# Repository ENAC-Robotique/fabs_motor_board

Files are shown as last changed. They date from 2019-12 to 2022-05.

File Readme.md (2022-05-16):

# Motor control board

STM32F767 based motor control board.

- control up to 3 DC motors
- 4 hardware encoder inputs.

**Holonomic drive:** Use the 3 motors, and the first 3 encoders.

**Differential drive:** Use the first 2 motors. Use the first 2 encodeurs for the motor encodeurs, and the last 2 for the odometry wheels (if applicable).

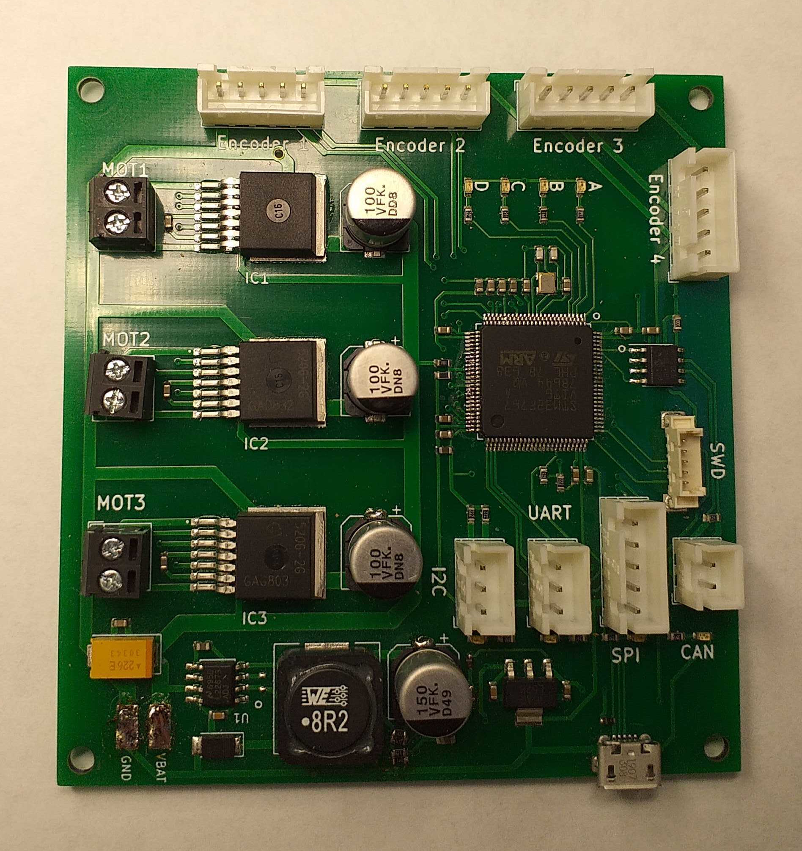
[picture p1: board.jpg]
board


Fetch all submodules with:

`git submodule update --init --recursive`

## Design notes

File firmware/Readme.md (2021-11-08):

Testeur software
================

To build the firmware, there is few thing you need to have.

First, Fetch ChibiOs and some third party contributions with `git submodule update --init --recursive`.

__Install Perl dependencies (used to generate board.h file from board.cfg):__

```
sudo apt update
sudo apt install libmodern-perl-perl libxml-libxml-perl
sudo perl -MCPAN -e 'install String::LCSS'
```

__Install GCC for ARM:__

`sudo apt install gcc-arm-none-eabi gdb-multiarch`

__Install STM32CubeMX__

Download and install SMT32CubeMx with admin rights (need to signup on st.com): [http://www.st.com/en/development-tools/stm32cubemx.html](http://www.st.com/en/development-tools/stm32cubemx.html).

Make sure it is installed in `/usr/local` for linux users (_not_ in your $HOME) or `C:\Program Files` for windows users.

Protobuf
--------

This firmware uses EmbeddedProto. See https://github.com/Embedded-AMS/EmbeddedProto

`git submodule update --init --recursive`

You need to install `protobuf-compiler`: `sudo apt install protobuf-compiler`

Then you need to run: `cd EmbeddedProto && ./setup.sh`

Run `make generate` to generate source code from protobuf files.

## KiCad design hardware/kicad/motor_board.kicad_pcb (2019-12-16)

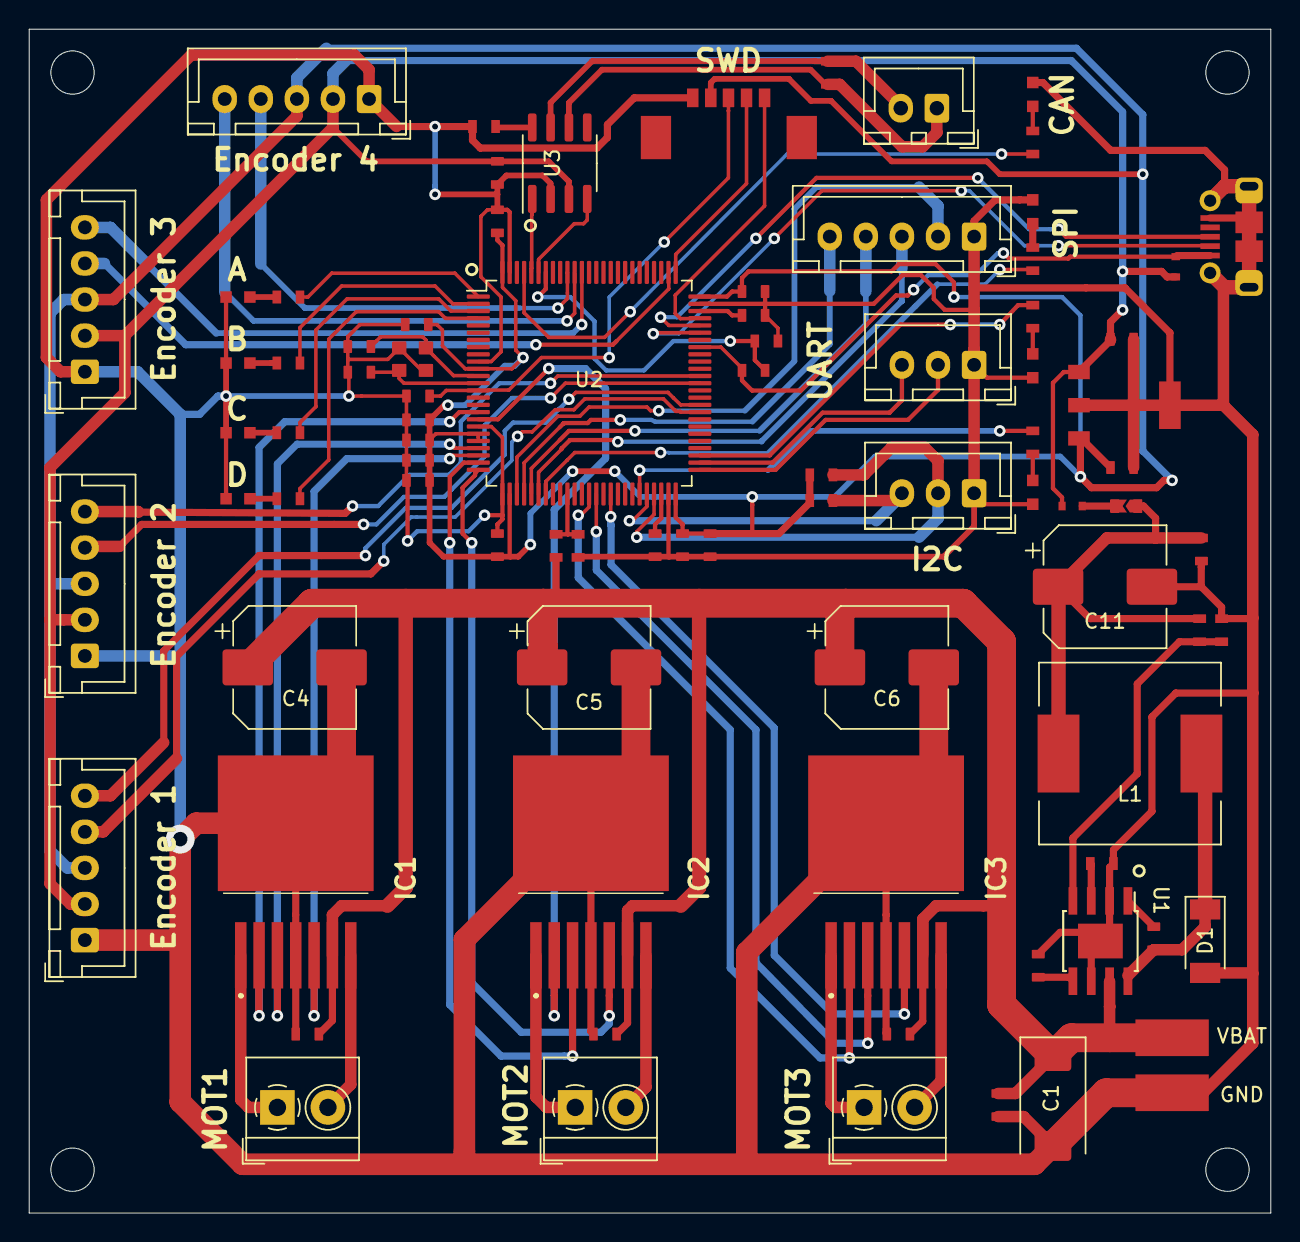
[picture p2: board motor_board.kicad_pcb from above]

Board: 2 copper layers, 86.0 x 82.0 mm, 84 parts (0 on the bottom side), 75 nets.

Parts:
C1: 22uF; CP_EIA-7343-31_Kemet-D
C2: 6.8nF; C_0603
C3, C12, C26, C28: 1uF; C_0603
C4, C5, C6: 100uF; CP_Elec_8x10
C7, C8, C9, C17, C19, C21, C22, C23, C25, C27, C29, C30: 100nF; C_0603
C10: 10nF; C_0603
C11: 120uF; CP_Elec_8x10
C13, C14: 2.2uF; C_0603
C15, C16: 18pF; C_0603
C18: 4.7uF; C_0603
C20: 470nF; C_0603
C24: 330nF; C_0603
D1: PMEG4050ETP; D_SOD-128
D2, D3: PMEG2010EB
IC1, IC2, IC3: TLE52062GAUMA1; TLE52052GAUMA1
IC4: LM3940IMP-3.3; LM3940IMP
J1: MOT1; TerminalBlock_4Ucon_1x02_P3.50mm_Horizontal
J2: MOT2; TerminalBlock_4Ucon_1x02_P3.50mm_Horizontal
J3: MOT3; TerminalBlock_4Ucon_1x02_P3.50mm_Horizontal
J4: UART; JST_XH_B3B-XH-A_1x03_P2.50mm_Vertical
J5: I2C; JST_XH_B3B-XH-A_1x03_P2.50mm_Vertical
J6: USB_Micro-B_Rec; USB_Micro-B_Molex_105017-0001
J7: ENC2; JST_XH_B5B-XH-A_1x05_P2.50mm_Vertical
J8: ENC3; JST_XH_B5B-XH-A_1x05_P2.50mm_Vertical
J9: ENC4; JST_XH_B5B-XH-A_1x05_P2.50mm_Vertical
J10: ENC8; JST_XH_B5B-XH-A_1x05_P2.50mm_Vertical
J11: SWD; PicoBlade_53398-0571
J12: SPI; JST_XH_B5B-XH-A_1x05_P2.50mm_Vertical
J13: CAN; JST_XH_B2B-XH-A_1x02_P2.50mm_Vertical
JP1: SolderJumper_2P; SolderJumper_2P_TrianglePads_0603
L1: 8.2uH; L_Wuerth_WE-PD-Typ-LS
LED1: KP-1608CGCK
LED2, LED5, LED6, LED7, LED8: KP-1608SYC
LED3: KP-1608SURC
LED4: KP-1608SEC
P1: Power_pads
Q1: 8Z_16MHz; Crystal_8Z
R1: infΩ; R_0603
R2, R3, R4: 1.5KΩ; R_0603
R5, R10: 2.2KΩ; R_0603
R6, R7, R8, R9, R13, R14, R17, R18: 390Ω; R_0603
R11: 10KΩ; R_0603
R12: 0Ω; R_0603
R15, R16: 2.2kΩ; R_0603
R19: 120Ω; R_0603
U1: LM22673MRE-ADJ; TI_SO-PowerPAD-8
U2: STM32F767VITx; LQFP-100_14x14mm_P0.5mm
U3: MCP2551-I-SN; SOIC-8_3.9x4.9mm_P1.27mm

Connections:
+3V3: C18.2, C19.2, C21.2, C22.2, C23.2, C24.1, C25.2, C26.2, C27.2, C28.1, C29.1, IC4.3, J7.3, J8.3, J9.3, J10.3, J11.2, R15.1, R16.1, U2.11, U2.20, U2.21, U2.27, U2.50, U2.75, U2.100
+5V: C20.1, C30.2, D2.1, D3.1, IC4.1, J7.2, J8.2, J9.2, J10.2, U3.3
/ADC_POWER: R10.1, R11.1, U2.35
/CAN1_RX: U2.95, U3.4
/CAN1_TX: U2.96, U3.1
/CANH: J13.2, R19.2, U3.7
/CANL: J13.1, R19.1, U3.6
/ENC2A: J7.4, U2.77
/ENC2B: J7.5, U2.89
/ENC3A: J8.5, U2.90
/ENC3B: J8.4, U2.91
/ENC4A: J9.4, U2.59
/ENC4B: J9.5, U2.60
/ENC8A: J10.4, U2.63
/ENC8B: J10.5, U2.64
/I2C2_SCL: J5.3, R15.2, U2.46
/I2C2_SDA: J5.2, R16.2, U2.47
/LED1: R6.2, U2.1
/LED2: R7.2, U2.2
/LED3: R9.2, U2.3
/LED4: R8.2, U2.4
/LED_CAN: R14.2, U2.97
/LED_I2C: R18.2, U2.45
/LED_SPI: R17.2, U2.32
/LED_UART: R13.2, U2.53
/NRST: C17.2, J11.3, U2.14
/PWM1A: IC1.3, U2.22
/PWM1B: IC1.5, U2.23
/PWM2A: IC2.3, U2.24
/PWM2B: IC2.5, U2.25
/PWM3A: IC3.3, U2.39
/PWM3B: IC3.5, U2.41
/SPI1_MISO: J12.4, U2.30
/SPI1_MOSI: J12.3, U2.31
/SPI1_NSS: J12.2, U2.28
/SPI1_SCK: J12.5, U2.29
/SWDCLK: J11.4, U2.76
/SWDIO: J11.5, U2.72
/TLE_EF_1: IC1.2, U2.17
/TLE_EF_2: IC2.2, U2.18
/TLE_EF_3: IC3.2, U2.38
/UART5_RX: J4.2, U2.51
/UART5_TX: J4.3, U2.52
/USB_DM: J6.2, U2.70
/USB_DP: J6.3, U2.71
/USB_VBUS: D3.2, J6.1, R4.2, U2.68
GND: C1.2, C2.1, C3.1, C4.2, C5.2, C6.2, C7.1, C8.1, C9.1, C11.2, C12.1, C13.2, C14.2, C15.1, C16.2, C17.1, C18.1, C19.1, C20.2, C21.1, C22.1, C23.1, C24.2, C25.1, C26.1, C27.1, C28.2, C29.2, C30.1, D1.2, IC1.4, IC1.8, IC2.4, IC2.8, IC3.4, IC3.8, IC4.2, IC4.4, J4.1, J5.1, J6.5, J6.6, J7.1, J8.1, J9.1, J10.1, J11.1, J12.1, LED1.1, LED2.1, LED3.1, LED4.1, LED5.1, LED6.1, LED7.1, LED8.1, P1.1, Q1.2, Q1.4, R1.1, R3.2, R5.1, R10.2, R12.2, U1.2, U1.6, U1.9, U2.10, U2.19, U2.26, U2.49, U2.74, U2.99, U3.2
unnamed: C3.2, U1.5
unnamed: C10.1, U1.1
unnamed: C10.2, D1.1, L1.1, U1.8
unnamed: C11.1, C12.2, JP1.1, L1.2, R2.1
unnamed: C13.1, U2.48
unnamed: C14.1, U2.73
unnamed: C15.2, Q1.1, U2.12
unnamed: C16.1, Q1.3, U2.13
unnamed: D2.2, JP1.2
unnamed: IC1.1, J1.1
unnamed: IC1.7, J1.2
unnamed: IC2.1, J2.1
unnamed: IC2.7, J2.2
unnamed: IC3.1, J3.1
unnamed: IC3.7, J3.2
unnamed: LED1.2, R6.1
unnamed: LED2.2, R7.1
unnamed: LED3.2, R8.1
unnamed: LED4.2, R9.1
unnamed: LED5.2, R13.1
unnamed: LED6.2, R14.1
unnamed: LED7.2, R17.1
unnamed: LED8.2, R18.1
unnamed: R1.2, U1.3
unnamed: R2.2, R3.1, U1.4
unnamed: R4.1, R5.2, U2.94
unnamed: R12.1, U3.8
VBAT: C1.1, C2.2, C4.1, C5.1, C6.1, C7.2, C8.2, C9.2, IC1.6, IC2.6, IC3.6, P1.2, R11.2, U1.7

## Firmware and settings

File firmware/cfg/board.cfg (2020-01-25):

MCU_MODEL = STM32F767VITx
#MCU_MODEL = STM32F767VGTx
CHIBIOS_VERSION = 3.0

HEADER
/*
 * Board identifier.
 */
#define BOARD_MOT_TRD
#define BOARD_NAME                  "Motor Board The Rusty Ducks V0.1"

/*
 * Board oscillators-related settings.
 */
#if !defined(STM32_LSECLK)
#define STM32_LSECLK                32768U
#endif

#define STM32_LSEDRV                (3U << 3U)

#if !defined(STM32_HSECLK)
#define STM32_HSECLK                16000000U
#endif

/*
 * Board voltages.
 * Required for performance limits calculation.
 */
#define STM32_VDD                   300U

/*
 * MCU type as defined in the ST header.
 */
#define STM32F767xx

CONFIG


# PIN NAME PERIPH_TYPE AF_NUMBER or
# PIN NAME FUNCTION PP_or_OPENDRAIN PIN_SPEED PULL_RESISTOR INITIAL_LEVEL AF_NUMBER
# SPEED : SPEED_VERYLOW, SPEED_LOW, SPEED_MEDIUM, SPEED_HIGH
#
# DEFAULT AND SYS
# 
# 'SYS' => ['ALTERNATE', 'PUSHPULL', 'SPEED_HIGH', 'FLOATING', 'LEVEL_HIGH'],
# 'ADC' => ['ANALOG', 'PUSHPULL', 'SPEED_HIGH', 'FLOATING', 'LEVEL_LOW'],
# 'PWM' => ['ALTERNATE', 'PUSHPULL', 'SPEED_HIGH', 'FLOATING', 'LEVEL_LOW'],
# 'ICU' => ['ALTERNATE', 'PUSHPULL', 'SPEED_HIGH', 'FLOATING', 'LEVEL_HIGH'],
# 'I2C' => ['ALTERNATE', 'OPENDRAIN', 'SPEED_HIGH', 'PULLUP', 'LEVEL_HIGH'],
# 'SPI' => ['ALTERNATE', 'PUSHPULL', 'SPEED_HIGH', 'FLOATING', 'LEVEL_HIGH'],
# 'UART' => ['ALTERNATE', 'PUSHPULL', 'SPEED_HIGH', 'PULLUP', 'LEVEL_HIGH'],
# 'OTG' => ['ALTERNATE', 'PUSHPULL', 'SPEED_HIGH', 'FLOATING', 'LEVEL_HIGH'],
# 'ETH' => ['ALTERNATE', 'PUSHPULL', 'SPEED_HIGH', 'FLOATING', 'LEVEL_HIGH'],
# 'FSMC' => ['ALTERNATE', 'PUSHPULL', 'SPEED_HIGH', 'FLOATING', 'LEVEL_HIGH'],
# 'SDIO' => ['ALTERNATE', 'PUSHPULL', 'SPEED_HIGH', 'PULLUP', 'LEVEL_HIGH'],
# 'SDIOCK' => ['ALTERNATE', 'PUSHPULL', 'SPEED_HIGH', 'FLOATING', 'LEVEL_HIGH'],
# 'CAN' => ['ALTERNATE', 'PUSHPULL', 'SPEED_HIGH', 'FLOATING', 'LEVEL_HIGH'],
# 'DCMI' => ['ALTERNATE', 'PUSHPULL', 'SPEED_HIGH', 'FLOATING', 'LEVEL_HIGH'],
# 'LED' => ['OUTPUT', 'PUSHPULL', 'SPEED_VERYLOW', 'FLOATING', 'LEVEL_LOW'],
# 'PASSIVE' => ['INPUT', 'PUSHPULL', 'SPEED_VERYLOW', 'FLOATING', 'LEVEL_LOW']);
#
# SYSTEM
A13     SWDIO     SYS  AF:SYS_JTMS-SWDIO
A14     SWCLK     SYS  AF:SYS_JTCK-SWCLK
#C14     OSC32_IN  OSC  
#C15     OSC32_OUT OSC  
H00     OSC_IN    OSC  
H01     OSC_OUT   OSC  

#DEFAULT
DEFAULT                 INPUT   PUSHPULL SPEED_VERYLOW PULLDOWN LEVEL_LOW  AF0


# ACTIVE PINS

PA09	USB_VBUS		INPUT    PULLDOWN  # //HARDTEST internal connection
PA11	OTG_FS_DM		OTG	 AF:USB_OTG_FS_DM # //HARDTEST internal connection
PA12	OTG_FS_DP		OTG	 AF:USB_OTG_FS_DP # //HARDTEST internal connection


# LEDS
PE02	LED_GREEN 	LED
PE03	LED_YELLOW	LED
PE04	LED_ORANGE	LED
PE05    LED_RED		LED
PE00	LED_CAN		LED
PC04	LED_SPI		LED
PB14	LED_UART	LED
PE15	LED_I2C		LED


# COMMUNICATION
PB08	CAN_RX		CAN	AF:CAN1_RX
PB09	CAN_TX		CAN	AF:CAN1_TX

PA04	SPI_NSS		SPI	AF:SPI1_NSS
PA05	SPI_CLK		SPI	AF:SPI1_SCK
PA06	SPI_MISO	SPI	AF:SPI1_MISO
PA07	SPI_MOSI	SPI	AF:SPI1_MOSI

PB13    UART_TX          UART            AF:UART5_TX 3.3_VOLTS
PB12    UART_RX          UART            AF:UART5_RX

PB10	I2C_SCL		I2C	AF:I2C2_SCL
PB11	I2C_SDA		I2C	AF:I2C2_SDA

# PWMS
PA00    PWM1A  PWM     AF:TIM5_CH1    3.3_VOLTS
PA01    PWM1B  PWM     AF:TIM5_CH2    3.3_VOLTS
PA02    PWM2A  PWM     AF:TIM5_CH3    3.3_VOLTS
PA03    PWM2B  PWM     AF:TIM5_CH4    3.3_VOLTS
PE09    PWM3A  PWM     AF:TIM1_CH1    3.3_VOLTS
PE11    PWM3B  PWM     AF:TIM1_CH2    3.3_VOLTS

# TLExxx ERROR FLAG INPUTS
PC02	EF1	INPUT	PULLUP	3.3_VOLTS
PC03	EF2	INPUT	PULLUP	3.3_VOLTS
PE08	EF3	INPUT	PULLUP	3.3_VOLTS



PA15    ENC2_A   ICU   PULLUP    AF:TIM2_CH1
PB03    ENC2_B   ICU   PULLUP    AF:TIM2_CH2
PB04    ENC3_A   ICU   PULLUP    AF:TIM3_CH1
PB05    ENC3_B   ICU   PULLUP    AF:TIM3_CH2
PD12    ENC4_A   ICU   PULLUP    AF:TIM4_CH1
PD13    ENC4_B   ICU   PULLUP    AF:TIM4_CH2
PC06    ENC8_A   ICU   PULLUP    AF:TIM8_CH1
PC07    ENC8_B   ICU   PULLUP    AF:TIM8_CH2

# Battery voltage
PB01    BAT_MEAS        ADC     ADC1_IN9

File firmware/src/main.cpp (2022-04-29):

#include <ch.h>
#include <hal.h>

#ifdef __cplusplus
extern "C" {
#endif
  #include "stdutil.h"		// necessaire pour initHeap
  #include "ttyConsole.h"		// fichier d'entête du shell
  
  
#ifdef __cplusplus
}
#endif

#include "encoders.h"
#include "communication.h"
#include "motors.h"
#include "utils.h"
#include "speed_control.h"
#include "power_check.h"

  //LEDS :
  //LINE_LED_GREEN,
  //LINE_LED_YELLOW,
  //LINE_LED_ORANGE,
  //LINE_LED_RED,
  //LINE_LED_CAN,
  //LINE_LED_SPI,
  //LINE_LED_UART,
  //LINE_LED_I2C,


static THD_WORKING_AREA(waBlinker, 304);
static void blinker (void *arg)
{
  (void)arg;
  chRegSetThreadName("blinker");

  while (true) {
    palToggleLine(LINE_LED_GREEN);
    chThdSleepMilliseconds(200);
  }
}


int main (void)
{

  halInit();
  chSysInit();
  initHeap();		// initialisation du "tas" pour permettre l'allocation mémoire dynamique 

  comm_init();
  consoleInit();	// initialisation des objets liés au shell

  chThdCreateStatic(waBlinker, sizeof(waBlinker), NORMALPRIO, &blinker, NULL); // lancement du thread 

  start_power_check();
  start_motor_control_pid();
  start_communication();

  // cette fonction en interne fait une boucle infinie, elle ne sort jamais
  // donc tout code situé après ne sera jamais exécuté.
  consoleLaunch();  // lancement du shell
  
  // main thread does nothing
  chThdSleep(TIME_INFINITE);
}

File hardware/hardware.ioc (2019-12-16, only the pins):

Mcu.UserName=STM32F767VITx
PA0/WKUP.Signal=S_TIM5_CH1
PA1.Signal=S_TIM5_CH2
PA11.Signal=USB_OTG_FS_DM
PA12.Signal=USB_OTG_FS_DP
PA13.Signal=SYS_JTMS-SWDIO
PA14.Signal=SYS_JTCK-SWCLK
PA15.Signal=S_TIM2_CH1_ETR
PA2.Signal=S_TIM5_CH3
PA3.Signal=S_TIM5_CH4
PA4.Signal=SPI1_NSS
PA5.Signal=SPI1_SCK
PA6.Signal=SPI1_MISO
PA7.Signal=SPI1_MOSI
PA9.Signal=USB_OTG_FS_VBUS
PB1.Signal=ADCx_IN9
PB10.Signal=I2C2_SCL
PB11.Signal=I2C2_SDA
PB12.Signal=UART5_RX
PB13.Signal=UART5_TX
PB14.Signal=GPIO_Output
PB3.Signal=S_TIM2_CH2
PB4.Signal=S_TIM3_CH1
PB5.Signal=S_TIM3_CH2
PB8.Signal=CAN1_RX
PB9.Signal=CAN1_TX
PC13.Signal=GPIO_Input
PC14/OSC32_IN.Signal=GPIO_Input
PC15/OSC32_OUT.Signal=GPIO_Input
PC2.Signal=GPIO_Input
PC3.Signal=GPIO_Input
PC4.Signal=GPIO_Output
PC6.Signal=S_TIM8_CH1
PC7.Signal=S_TIM8_CH2
PD12.Signal=S_TIM4_CH1
PD13.Signal=S_TIM4_CH2
PE0.Signal=GPIO_Output
PE11.Signal=S_TIM1_CH2
PE12.Signal=GPIO_Input
PE13.Signal=S_TIM1_CH3
PE14.Signal=S_TIM1_CH4
PE15.Signal=GPIO_Output
PE2.Signal=GPIO_Output
PE3.Signal=GPIO_Output
PE4.Signal=GPIO_Output
PE5.Signal=GPIO_Output
PE6.Signal=GPIO_Input
PE8.Signal=GPIO_Input
PE9.Signal=S_TIM1_CH1
PH0/OSC_IN.Signal=RCC_OSC_IN
PH1/OSC_OUT.Signal=RCC_OSC_OUT

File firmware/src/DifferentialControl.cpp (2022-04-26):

#include "DifferentialControl.h"
#include "OdometryDiff.h"
#include "motors.h"
#include "encoders.h"
#include "hal.h"
#include "communication.h"
#include "BytesWriteBuffer.h"
#include "messages.h"
#include "utils.h"

extern "C" {
  #include "printf.h"
  #include "globalVar.h"
  #include "stdutil.h"
    
}

using namespace protoduck;

#define SETPOINT_VALIDITY 1000  //ms
#define CONTROL_PERIOD 50 //ms
#define ODOMETRY_PERIOD 50 //ms

void DifferentialControl::init() {

  initPwms();

  setMot1(0);
  setMot2(0);
  setMot3(0);

  lastTime_odometry = chVTGetSystemTime();
  lastTime_motors = chVTGetSystemTime();
  setpoint_time = chVTGetSystemTime();

  l_pid.init(30, 2000);
  r_pid.init(30, 2000);

  auto set_setpoint_cb = [this](Message& msg) {
    if (msg.has_speed() && msg.msg_type() == Message::MsgType::COMMAND) {
          auto vx = msg.speed().vx();
          auto vy = msg.speed().vy();
          auto vtheta = msg.speed().vtheta();
          //chprintf ((BaseSequentialStream*)&SDU1, "Speed cmd: %f, %f, %f\r\n\r\n", vx, vy, vtheta);
          // acquire lock ?!
          set_speed_setPoint(vx, vy, vtheta);
      }
  };

  auto set_pid_gains_cb = [this](Message& msg) {
    if(msg.has_motor_pid() && msg.msg_type() == Message::MsgType::COMMAND) {
          auto motor_no = msg.motor_pid().motor_no();
          auto feedforward = msg.motor_pid().feedforward();
          auto kp = msg.motor_pid().kp();
          auto ki = msg.motor_pid().ki();
          auto kd = msg.motor_pid().kd();
          // acquire lock ?!
          set_pid_gains(motor_no, feedforward, kp, ki, kd);
      }
  };

  register_callback(set_setpoint_cb);
  register_callback(set_pid_gains_cb);
}

void DifferentialControl::set_speed_setPoint(double vx, double vy, double vtheta) {
    speed_setPoint = vx;
    omega_setPoint = vtheta;


    double spl = speed_setPoint + WHEELBASE*omega_setPoint/2;
    double spr = speed_setPoint - WHEELBASE*omega_setPoint/2;


    l_pid.set_setpoint(spl);
    r_pid.set_setpoint(spr);

    setpoint_time = chVTGetSystemTime();
}

// TODO omega ?
// message en parametre ?
void DifferentialControl::set_pid_gains(uint32_t motor_no, double feedforward, double kp, double ki, double kd) {
    if(motor_no == 0) {
      l_pid.set_gains(feedforward, kp, ki, kd);
      r_pid.set_gains(feedforward, kp, ki, kd);
    } else if(motor_no == 1) {
      l_pid.set_gains(feedforward, kp, ki, kd);
    } else if(motor_no == 2) {
      r_pid.set_gains(feedforward, kp, ki, kd);
    }
}

void DifferentialControl::speed_control(OdometryDiff* odometry) {
  systime_t now = chVTGetSystemTime();
  
  
  
  // set speed setpoint to 0 is no speed command has been received since a while.
  if(chVTTimeElapsedSinceX(setpoint_time) > chTimeMS2I(SETPOINT_VALIDITY)) {
    set_speed_setPoint(0, 0, 0);
  }

  if(chVTTimeElapsedSinceX(lastTime_odometry) > chTimeMS2I(ODOMETRY_PERIOD)) {
    double elapsed_odometry = chTimeI2MS(chVTTimeElapsedSinceX(lastTime_odometry))/1000.0;
    odometry->update_pos(elapsed_odometry);
    lastTime_odometry = now;
  }

  if(chVTTimeElapsedSinceX(lastTime_motors) > chTimeMS2I(CONTROL_PERIOD)) {
    double elapsed_motors = chTimeI2MS(chVTTimeElapsedSinceX(lastTime_motors))/1000.0;

    odometry->update_mot(elapsed_motors);

    double speed_left = odometry->get_speed_left();
    double speed_right = odometry->get_speed_right();
    double cmd_left =  l_pid.update(speed_left);
    double cmd_right = r_pid.update(speed_right);
    setMot1(cmd_left);
    setMot2(-cmd_right);

    //chprintf ((BaseSequentialStream*)&SDU1, "speeds = %f\t%f\r\n", speed_left, speed_right);

    //sendMotorsSpeed(speed_left, speed_right, 0);
    //sendMotorsCmd(l_pid.get_setpoint(), l_pid.get_precommand(), 0);

    lastTime_motors = now;
  }
}

msg_t DifferentialControl::sendMotorsSpeed(double v1, double v2, double v3) {
  Message msg;
  auto& motors_speed = msg.mutable_motors_speed();
  motors_speed.set_v1(v1);
  motors_speed.set_v2(v2);
  motors_speed.set_v3(v3);
  return post_message(msg, Message::MsgType::STATUS, TIME_IMMEDIATE);
}

msg_t DifferentialControl::sendMotorsCmd(double cmd1, double cmd2, double cmd3) {
  Message msg;
  auto& motors_cmd= msg.mutable_motors_cmd();
  motors_cmd.set_cmd1(cmd1);
  motors_cmd.set_cmd2(cmd2);
  motors_cmd.set_cmd3(cmd3);
  return post_message(msg, Message::MsgType::STATUS, TIME_IMMEDIATE);
}

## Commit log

2019-11-18 Hopefully finish schematic.
    [motor_board.sch]
2019-11-18 Begins PCB design.
    [motor_board.kicad_pcb]
2019-11-18 Adds diodes to power board via usb.
    [motor_board.sch]
2019-11-18 Finish PCBV0.1
    [motor_board.kicad_pcb]
2019-11-18 Edit for Stencil
    [motor_board.kicad_pcb]
2019-12-16 minor changes
    [motor_board.kicad_pcb, motor_board.sch]
2019-12-16 Back to original size (no stencil)
    [motor_board.kicad_pcb]
2020-01-25 Adds STM32 docs.
2020-01-25 Begins firmware.
    [board.cfg]
2020-01-25 Odometry for diff drive - no coding wheels.
2020-01-25 Adds power voltage check.
2021-11-08 Set motor command range to [-100, 100]
2021-11-08 Move power check in its own file.
2021-11-09 Convert motor.c to cpp and use templates.
2021-11-09 Odometry and stuff.
2021-11-17 Use and tune coding wheels.
2021-11-19 comment printfs
2021-11-20 PID filter input and saturate integrator.
2022-03-23 change motors directions.
2022-04-20 Remove CMSIS ARM math.
2022-04-20 Make holonomic odometry.
2022-04-21 [OdometryHolo] Speed in robot frame.
2022-04-26 [Diff] Fix time error.
    [DifferentialControl.cpp]
2022-04-28 Update ChibiOS to 21.11
    [board.cfg]
2022-05-19 Magic number to compensate for different motor.
2022-05-19 Tune Holo odometry
2022-05-19 do not report motors speed
